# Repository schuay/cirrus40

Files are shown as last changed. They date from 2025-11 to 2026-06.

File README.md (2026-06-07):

# Cirrus40 Keyboard

The Cirrus40 is a 40% split mechanical keyboard, with an ortholinear layout and a focus on usable rotary encoders.

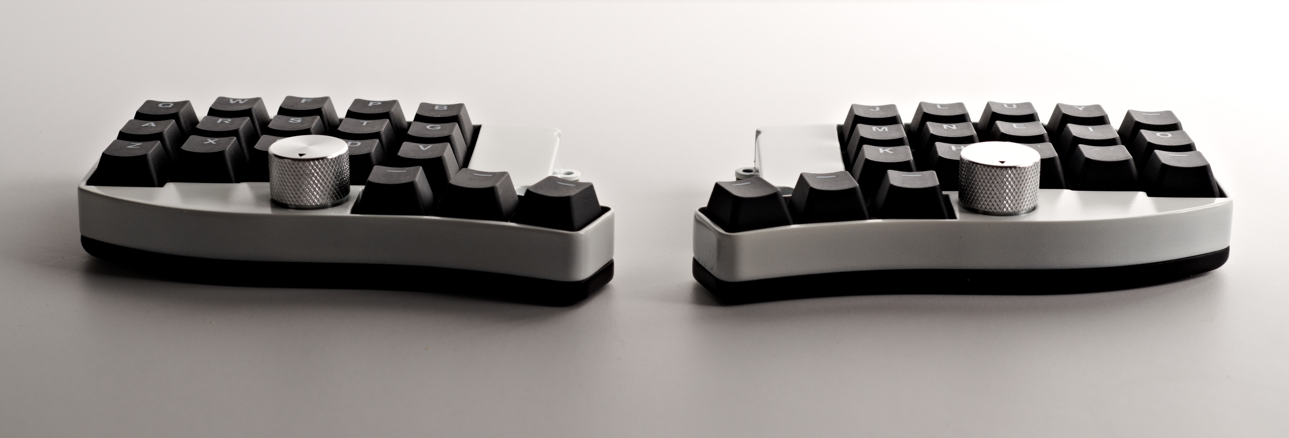
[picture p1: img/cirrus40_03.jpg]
cirrus40img0

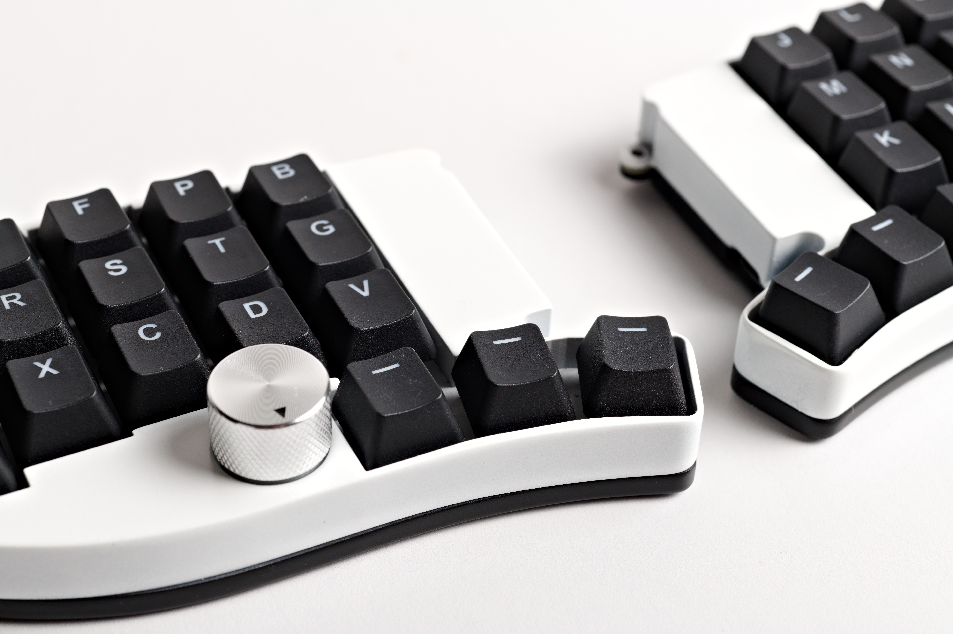
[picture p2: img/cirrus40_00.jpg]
cirrus40img1

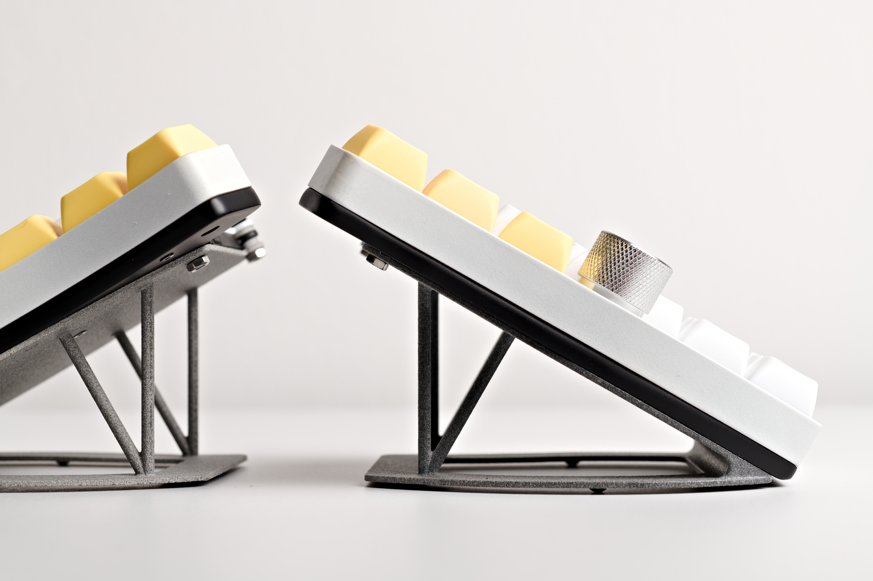
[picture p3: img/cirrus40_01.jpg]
cirrus40img2

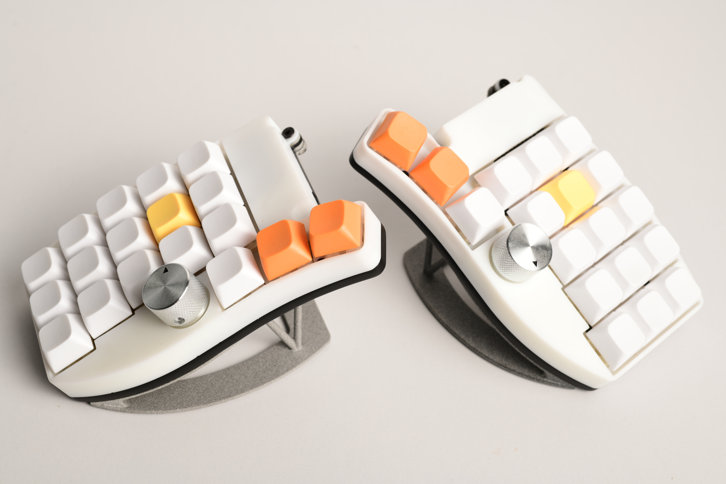
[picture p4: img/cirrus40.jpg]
cirrus40img3

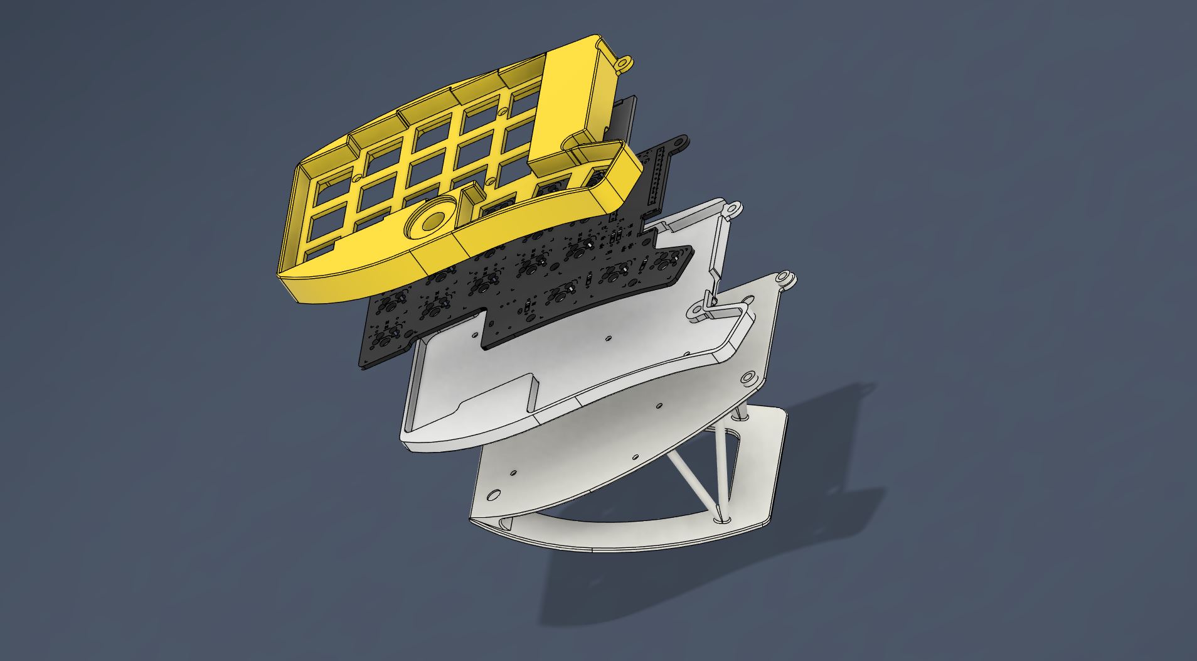
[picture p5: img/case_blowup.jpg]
case_blowup


## Design Considerations

- A **3x thumb cluster** where each key is equally usable and comfortable to reach.
- **Rotary encoders** under the palms are nicely reachable without moving hands from the homerow position. One-handed use together with homerow modifiers (think: switching tabs, workspaces; word-by-word navigation, selection, and deletion). Hardware debouncing for the perfect input signal; no more missed transitions.
- A **full 3d printed case** protects the internals.
- An **optional 3d printed 30deg tenting stand** for rock-solid tenting. The tenting stand integrates perfectly with the case.
- An **ortholinear** layout. Why not columnar stagger: it's comfortable at rest, but increases separation between the pinky and ring fingers in motion.
- A **hot-pluggable wired USB-C interconnect** between halves. USB-C cables are widely available.
- Support for **both wired and wireless** operation.
- Simple tenting using M3 screws.
- No toys: no LEDs, no displays.
- Only widely available and inexpensive parts.

The Cirrus40 combines some of the favorite aspects of my previous builds (the Cheapino's thumb cluster and the Lotus58's key layout and USB-C interconnect). I got a bit fixated on optimizing encoder precision and ergonomics, which is why you'll see the hardware debouncing circuit, the below-palm position, and the strong recommendation for quality Alps encoders.

## Firmware

**QMK**: [qmk_firmware](https://github.com/schuay/qmk_firmware/tree/add_cirrus40). My own keymap is available as an example at [qmk_userspace](https://github.com/schuay/qmk_userspace).

**ZMK**: Contributions welcome. [zmk-config](https://github.com/schuay/zmk-config) hasn't been updated for Cirrus40 Revision 2 yet.

## Required Files

All files required for manufacture are located in the most recent release directory.

- **[PCB Gerber Files](releases/20251220/pcb-gerber.zip)**: For manufacturing the printed circuit boards.
- **[3D Case/Stand Files](releases/20251220/case-steps.tar.xz)**: STEP files for printing the case and optional tenting stand.

## Ordering guide

TLDR: PCB and case manufacturing from JLCPCB, electronics components from LCSC, and the rest from AliExpress with Choice shipping.

- [jlcpcb.com](jlcpcb.com):
  - For the PCB: it's safe to stick with default values. 
  - For the case: I used 9600 Resin (Spray Painting-Matte-Black) for the case and PA12-HP Nylon for the tenting stand with good results. Please let me know if you experiment with other materials.
- [lcsc.com](lcsc.com): See [doc/bom.csv](doc/bom.csv) for more info. Note that the [USB-C connector I used](https://www.lcsc.com/product-detail/C963373.html) is currently out of stock and NOT included in [doc/bom.csv](doc/bom.csv).
- [aliexpress.com](aliexpress.com): Great for switches, keycaps, encoder heads, the RP2040 ProMicro MCU, MCU pin headers, screws, spacers, nuts, etc. I've had good experiences with "Choice" shipping.

Note: jlcpcb.com and lcsc.com offer combined shipping; this is not recommended, as it was more complex, more expensive, and slower when I tried it.

## Build guide

A detailed, step-by-step build guide is not yet available. Contributions on this front are very welcome!

However, the build process is straightforward for those with some experience in hand-soldering keyboards. The soldering difficulty is medium-to-easy; the surface-mount components are in a large (0805) package and are suitable for hand-soldering. The USB-C connector is also simpler than it looks: the wiring is such that all data pins can simply be bridged together (i.e. precise drag-soldering is not strictly needed).

I usually do the USB-C connector and SMD components first, followed by diodes and hotswap sockets; and finally the MCU plus socket and encoders. All components (except the encoder) go on the bottom side of the PCB. Consult the kicad files if something is unclear. A multimeter is good to have around for verification and error search.

## Bill of Materials

A single keyboard build costs around 80EUR including shipping and customs from JLCPCB and LCSC.

**Core Components**
| Part | Quantity | Notes |
| --- | --- | --- |
| Reversible PCB | 2 | From the Gerber files |
| 3D Printed Case | 1 | From the STEP files. Tenting stand is optional. |
| MX switches | 36 | |
| MX hotswap sockets | 36 | |
| EC11 rotary encoders | 2 | **ALPS EC11E15244G1** is strongly recommended. |
| Encoder knobs | 2 | |
| 1N4148 or 1N4148W diodes | 40 | SOD-123 or SOD-323 package |
| 100nF capacitors | 4 | 0805 package |
| 10kOhm resistors | 4 | 0805 package |
| 8.2kOhm resistors | 4 | 0805 package |
| MCU Sockets / Pin Headers | 2 sets | For socketing the microcontrollers |

**Wired Build Components**
| Part | Quantity | Notes |
| --- | --- | --- |
| Pro Micro (RP2040) MCU | 2 | |
| Ferrite beads | 4 | 0805 package, e.g., 220Ω@100MHz |
| USB-C mid-mount connector | 2 | e.g., LCSC C963373 |
| ESD protection diode | 2 | e.g., LCSC C558418 |

**Wireless Build Components**
| Part | Quantity | Notes |
| --- | --- | --- |
| nice!nano v2 MCU | 2 | |
| LiPo Battery | 2 | 301230 (110 mAh) size recommended |
| Power slide switch | 2 | e.g., LCSC C431540 |

**Hardware**
| Part | Quantity | Notes |
| --- | --- | --- |
| M2x4mm screws | 20 | Use M2x6mm for the 4 case holes if using the tenting stand |
| M2x7mm spacers | 10 | |
| M3 screws and nuts | 4 (opt) | For basic, non-stand tenting |

## Release history

Released files can be found in the releases/ directory.

- [releases/20251220](releases/20251220): Revision 2. 3x5+3 with a full 3d printed case and 30deg tenting stand. Hardware encoder debouncing.
- [releases/20251001](releases/20251001): Revision 1. 3x6+3 with a sandwich case.

## Revision 1 Gallery
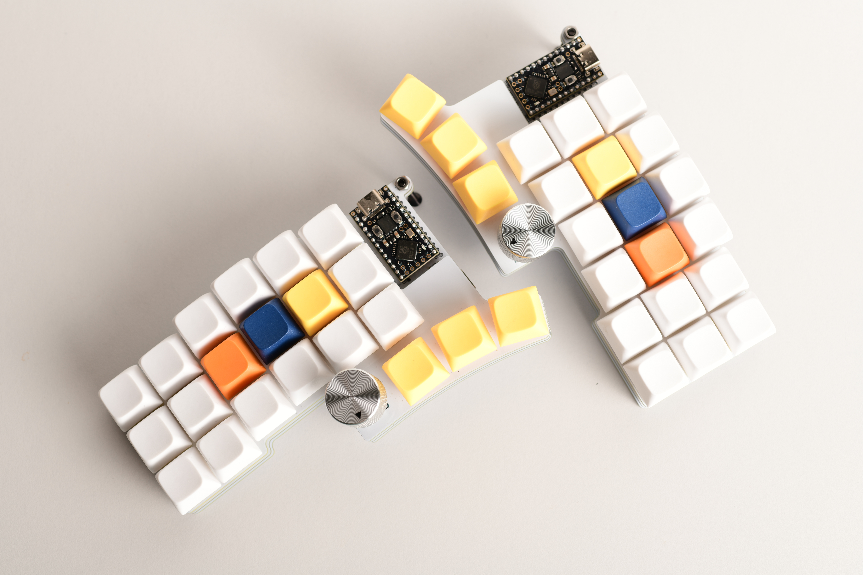
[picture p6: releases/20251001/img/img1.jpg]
cirrus40 img1

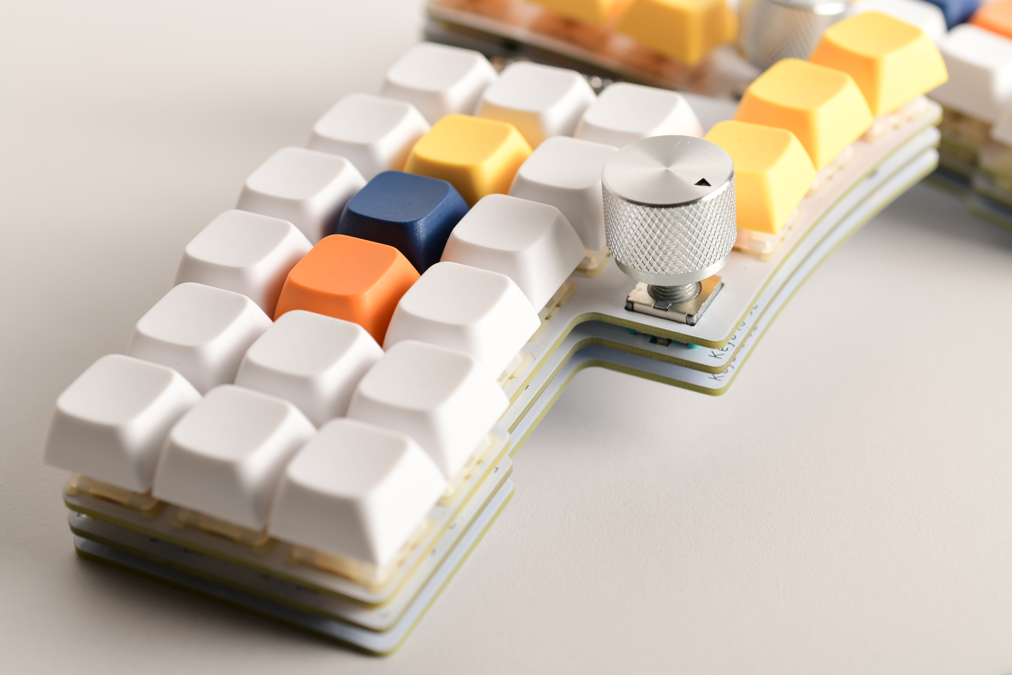
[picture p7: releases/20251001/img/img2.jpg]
cirrus40 img2

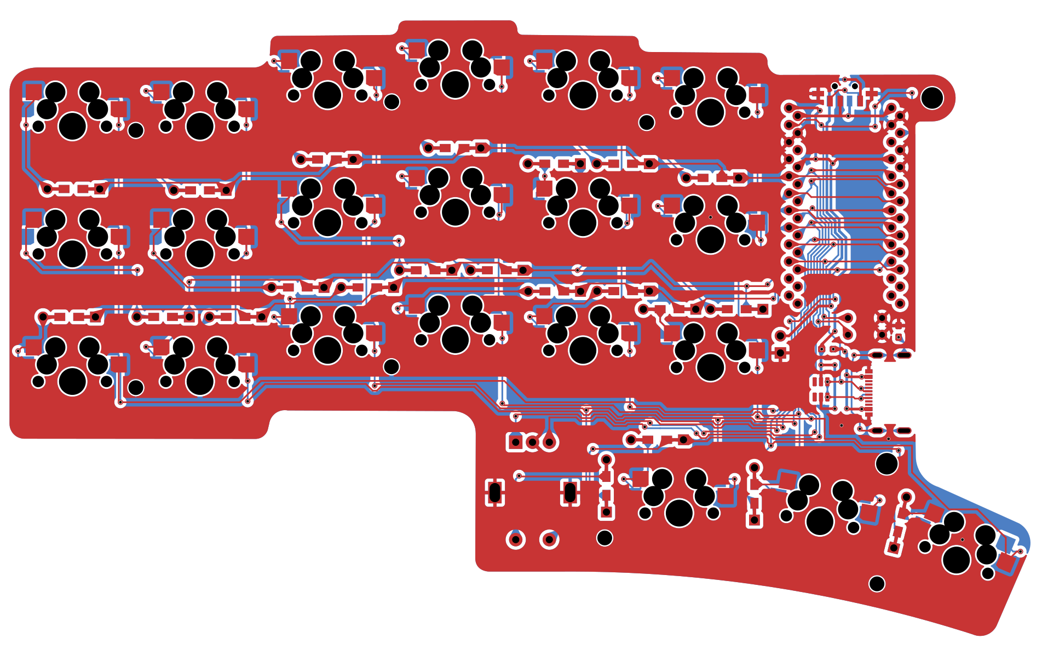
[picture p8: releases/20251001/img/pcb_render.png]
cirrus40 pcb render


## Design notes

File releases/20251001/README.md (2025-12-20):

# Cirrus40 Keyboard

The Cirrus40 is a 40% split mechanical keyboard, featuring an ortholinear layout and rotary encoders designed as first-class citizens.

cirrus40 img1
cirrus40 img2

## Design Considerations

- A **3x thumb cluster** where each key is equally usable and comfortable to reach.
- **Rotary encoders** under the palms are nicely reachable without moving hands from the homerow position. One-handed use together with homerow modifiers (think: switching tabs, workspaces; word-by-word navigation, selection, and deletion).
- An **ortholinear** layout. Why not columnar stagger: it's comfortable at rest, but increases separation between the pinky and ring fingers in motion.
- A **hot-pluggable wired interconnect** between halves, since it's not acceptable that unplugging a cable at the wrong time can destroy your keyboard.
- Support for **both wired and wireless** operation. For wired: the interconnect is ESD protected. For wireless: the battery can be physically disconnected using a switch.
- Simple tenting using M3 screws.
- No toys: no LEDs, no displays.
- Only widely available and inexpensive parts.

cirrus40 pcb render

## Why not..

There are many great keyboard designs out there. But keyboards are highly personal, and none of them hit all the marks for me. So why not...

- The **cheapino**: this was the first keyboard I built. It's very beginner friendly due to the large components and a great first build. However, since the entire matrix is routed onto one MCU, and particularly since the RJ45 only has 7 pins available for signals, the design has to make compromises such as the duplex matrix, and connecting the rotary encoder through the matrix instead of dedicated pins. Also, there is only one encoder in an inconvenient position, and I didn't like the
  columnar stagger. The thumb cluster is great though, and I've reused it here.
- **Lotus58**: Inconvenient thumb cluster and encoder placement, a number row, and unnecessary features like displays and LEDs. I learnt a lot from this design though, particularly the USB-C interconnect design was lifted from here.
- **Kyria**: I was eyeing this one for a while, and I love the design decisions. But, it's not open source. Also, the palm encoder position is too far away from the thumb, and it uses pronounced columnar stagger.
- **Corne**: Only two usable thumb keys, and recent versions require expensive factory assembly.
- Any pure wireless keyboard: unfortunately ZMK is not as mature as I'd hoped.

## Release history

Released files can be found in the releases/ directory.

- [releases/20251220](releases/20251220): Revision 2. 3x5+3 with a full 3d printed case and 30deg tenting stand. Hardware encoder debouncing.
- [releases/20251001](releases/20251001): Revision 1. 3x6+3 with a sandwich case.

## Bill of Materials

- 2 each of the PCB, and top and bottom plates
- 42 MX switches and keycaps
- 42 MX hotswap sockets
- 2 EC11 encoders and encoder heads
- 44 1N4148 or 1N4148W diodes
- 4 100nF capacitors
- MCU sockets

For the wired build, additionally:
- 2 RP2040 Pro Micro MCUs
- 4 20mΩ 70Ω@100MHz 0603 ferrite beads
- 2 USB-C midmount connectors, e.g. https://www.lcsc.com/product-detail/C963373.html
- 2 ESD diodes, e.g. https://www.lcsc.com/product-detail/C558418.html

For the wireless build, additionally:
- 2 nice!nano v2 MCUs
- 2 Lithium-Polymer Battery 301230 (110 mAh)
- 2 slide switches: https://www.lcsc.com/product-detail/C431540.html

For assembly:
- 28 M2x4mm screws
- 14 M2x3mm spacers
- 4 M3 screws and nuts for tenting

Note you can simply combine both builds if you're undecided and want to be able to swap MCUs and batteries.

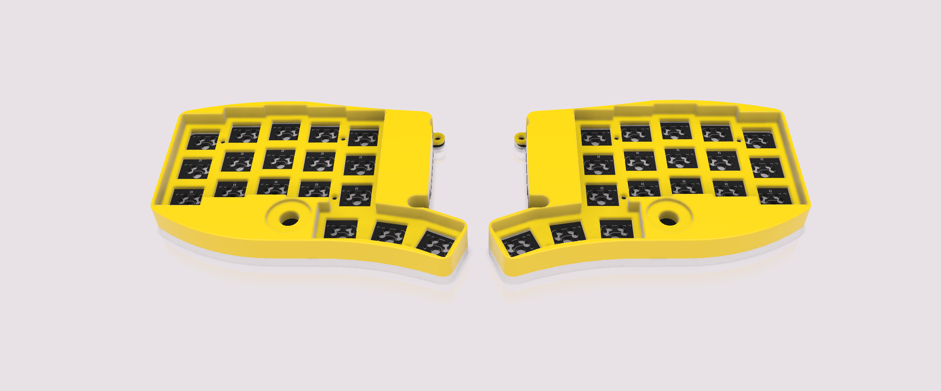
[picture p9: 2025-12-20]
img/case_render.png

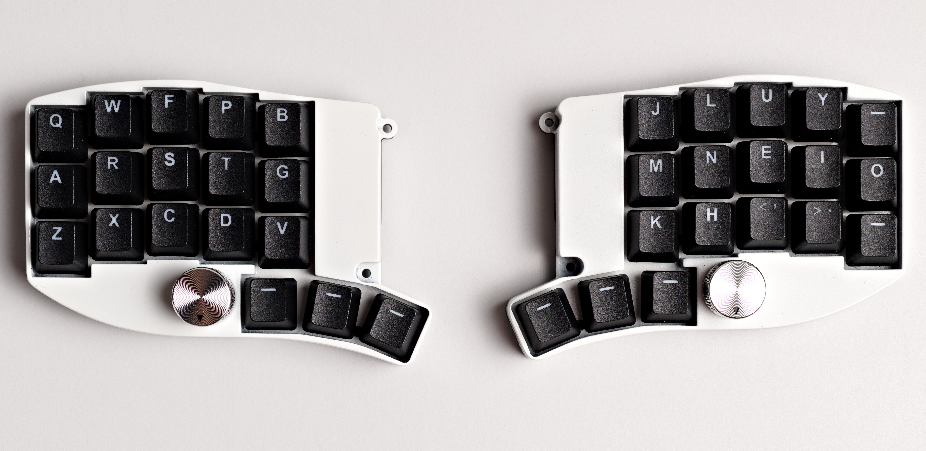
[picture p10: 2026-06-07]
img/cirrus40_04.jpg

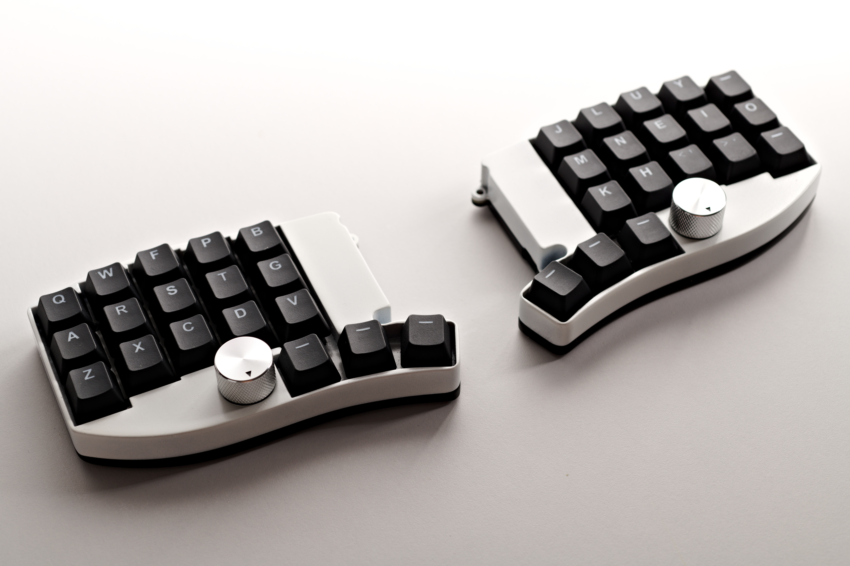
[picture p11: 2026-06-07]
img/cirrus40_02.jpg

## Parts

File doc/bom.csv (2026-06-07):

Cirrus40v2 |  |  |  |  |  |  |  |  |  | LCSC BOM Quotation
 |  |  |  |  |  |  |  |  |  | BOM Date Created：31/12/25 17:56:03 |  |  |  | BOM Export Date: 31/12/25 18:03:18 |  |  |  | The matching result is a real-time query result, availability and prices may fluctuate. Backorder items are estimated prices for your reference, please submit "Create Quote" to get the real price. All information is provided "as is" and is subject to change without notice. Any use made of the information provided is without recourse to LCSC and at the user's risk.
 |  |  |  |  |  |  |  |  |  | EST TOTAL :$6.07 |  |  |  | Website：https://www.lcsc.com/bom
Uploaded data |  |  |  |  |  |  |  |  |  | LCSC Matching Results
LCSC# | Mfr. | Mrf# | Description | Package | Value | Customer Part Number | Quantity | Target Price(EUR) | Target Lead Time(Business Days) | Mrf# | Mfr. | Order Qty. | Unit Price(EUR) | Ext.Price(EUR) | LCSC# | Package | Min | Mult | SPQ | Availability | Stock Status | Customer Notes | Description | Matched status | Product Link
 |  |  |  |  |  | - | 2 |  |  | EC11E15244G1 | ALPSALPINE | 2 | 1.8759 | 3.75 | C370970 | Through Hole | 1 | 1 | 120 | 2121 | In Stock |  | Through Hole Encoders RoHS | Exact Matches | https://www.lcsc.com/product-detail/C370970.html
 |  |  |  |  |  | - | 4 |  |  | CC0805KRX7R9BB104 | YAGEO | 100 | 0.0043 | 0.43 | C49678 | 0805 | 100 | 100 | 4000 | 8486200 | In Stock |  | 100nF ±10% 50V Ceramic Capacitor X7R 0805 | Exact Matches | https://www.lcsc.com/product-detail/C49678.html
 |  |  |  |  |  | - | 4 |  |  | BLM21PG221SN1D | muRata | 50 | 0.0145 | 0.73 | C85840 | 0805 | 50 | 50 | 4000 | 1164100 | In Stock |  | 220Ω@100MHz 1 Line Ferrite Bead 0805 2A 45mΩ | Exact Matches | https://www.lcsc.com/product-detail/C85840.html
 |  |  |  |  |  | - | 4 |  |  | RS-05K1002FT | FH | 100 | 0.0018 | 0.18 | C115309 | 0805 | 100 | 100 | 5000 | 1124300 | In Stock |  | 10kΩ ±1% 125mW 0805 Thick Film Resistor | Exact Matches | https://www.lcsc.com/product-detail/C115309.html
 |  |  |  |  |  | - | 4 |  |  | 0805W8F8201T5E | UNI-ROYAL | 100 | 0.0017 | 0.17 | C17828 | 0805 | 100 | 100 | 5000 | 353200 | In Stock |  | 8.2kΩ ±1% 125mW 0805 Thick Film Resistor | Exact Matches | https://www.lcsc.com/product-detail/C17828.html
 |  |  |  |  |  | - | 40 |  |  | 1N4148 | LGE | 50 | 0.0079 | 0.40 | C402212 | DO-35 | 50 | 50 | 5000 | 82100 | In Stock |  | Diode 75V 150mA Through Hole DO-35 | Exact Matches | https://www.lcsc.com/product-detail/C402212.html
 |  |  |  |  |  | - | 2 |  |  | SRV05-4 | TECH PUBLIC | 20 | 0.0206 | 0.41 | C558418 | SOT-23-6 | 20 | 20 | 3000 | 183460 | In Stock |  | 20VC Clamp 3A Ipp ESD DIODE SOT-23-6 | Exact Matches | https://www.lcsc.com/product-detail/C558418.html

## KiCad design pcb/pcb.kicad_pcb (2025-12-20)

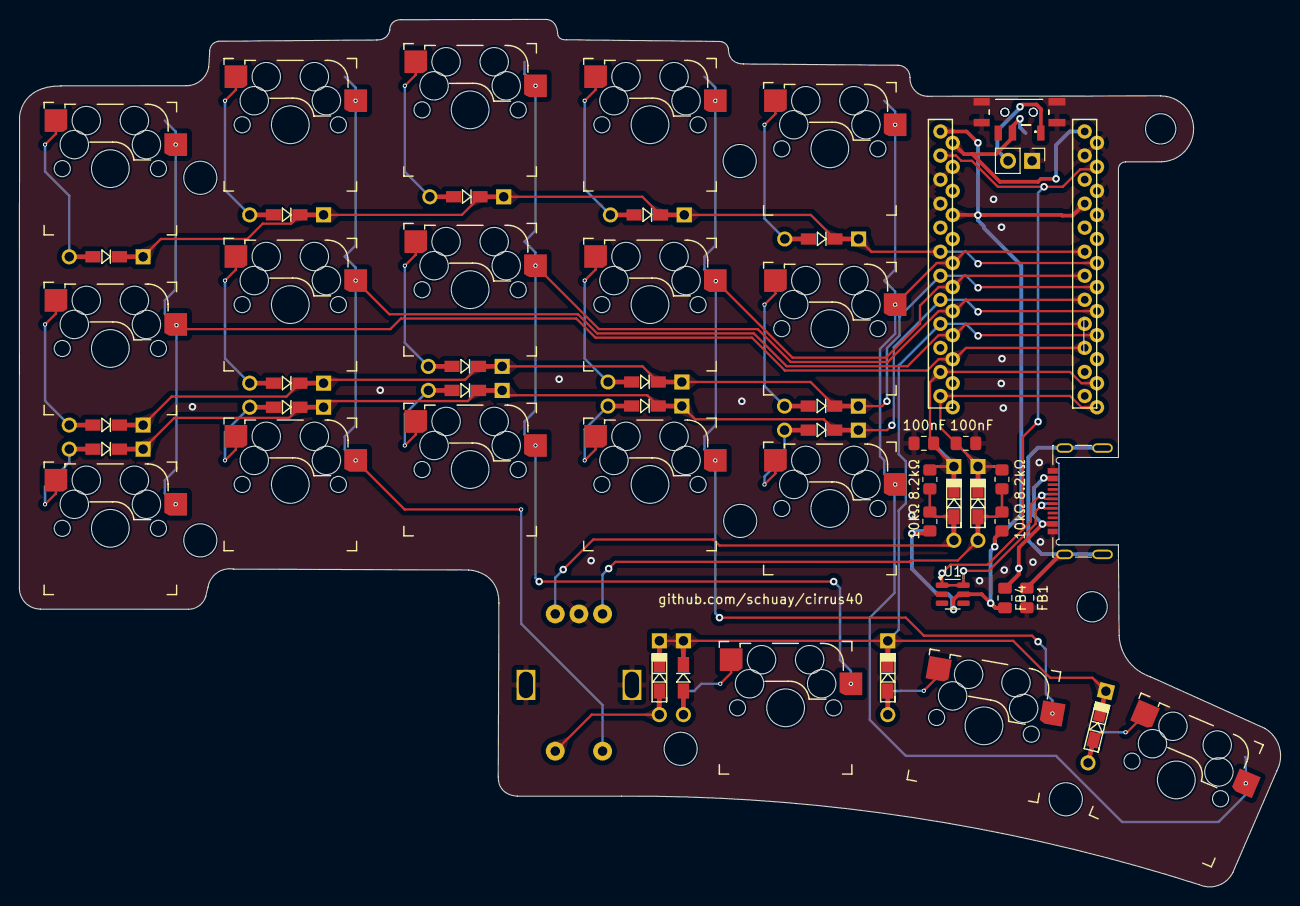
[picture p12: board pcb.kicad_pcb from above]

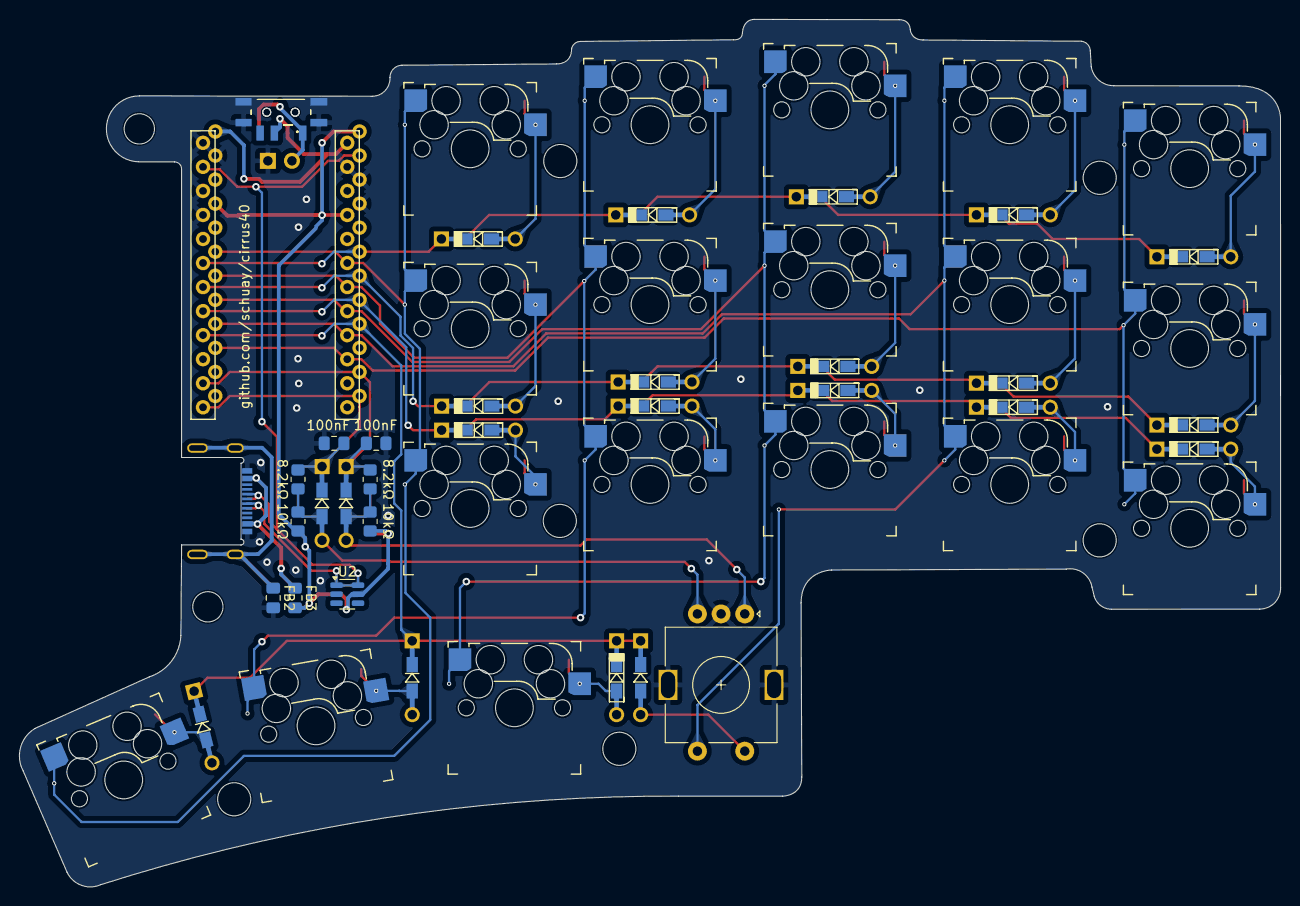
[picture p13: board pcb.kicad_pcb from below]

Board: 2 copper layers, 133.2 x 91.6 mm, 63 parts (45 on the bottom side), 39 nets.

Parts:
8.2kΩ, 8.2kΩ#2, 8.2kΩ#3, 8.2kΩ#4: 8kOhm; R_0805_2012Metric_Pad1.20x1.40mm_HandSolder
10kΩ, 10kΩ#2, 10kΩ#3, 10kΩ#4: 10kOhm; R_0805_2012Metric_Pad1.20x1.40mm_HandSolder
100nF, 100nF#2, 100nF#3, 100nF#4: 470nF; C_0805_2012Metric_Pad1.18x1.45mm_HandSolder
D1, D2, D3, D4, D5, D6, D7, D8, D9, D10, D11, D12, D13, D14, D15, D16, D17, D18, D19, D20, D21: DIODE; Diode-dual
ENC1: RotaryEncoder_Switch_MP; RotaryEncoder_Alps_EC11E-Switch_Vertical_H20mm
FB1, FB2, FB3, FB4: Ferrite Bead; C_0805_2012Metric_Pad1.18x1.45mm_HandSolder
J1: USB_C_Receptacle_USB2.0_16P; Molex-216990_GCT-USB45xx_HRO-TYPE-C-31-M-13x-PiMicro_1_DOUB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
J2: Conn_01x02; PinHeader_1x02_P2.54mm_Vertical
K1, K2, K3, K4, K5, K6, K7, K8, K9, K10, K11, K12, K13, K14, K15, K16, K17, K18: SW_Push; SW_MX_HotSwap_Reversible
S1, S2: MSK12C02
U1, U2: SRV05-4; SOT-23-6
U3: ProMicro; ProMicro_Reversible_orig

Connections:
/Batt: J2.2, S1.NC, S2.NC
/VCC_LINK: FB3.1, FB4.1, J1.A4 (VBUS), J1.A9 (VBUS), J1.B4 (VBUS), J1.B9 (VBUS)
Battery: S1.COM, S2.COM, U3.5V
COL0: K15.1, K16.1, K17.1, K18.1, U3.28 (GP28)
COL1: K11.1, K12.1, K13.1, K14.1, U3.27 (GP27)
COL2: K7.1, K8.1, K9.1, K10.1, U3.26 (GP26)
COL3: ENC1.S1, K4.1, K5.1, K6.1, U3.22 (GP22)
COL4: K1.1, K2.1, K3.1, U3.20 (GP20)
DATA: J1.A7 (D-), J1.B7 (D-), U1.1 (IO1), U1.6 (IO4), U2.1 (IO1), U2.6 (IO4), U3.1 (GP1)
ENCA: 8.2kΩ#2.1, 8.2kΩ#3.1, 10kΩ#2.2, 10kΩ#4.2, D12.1 (K), ENC1.A
ENCA_DB: 8.2kΩ#2.2, 8.2kΩ#3.2, 100nF#2.1, 100nF#3.1, D12.2 (A), U3.8 (GP8)
ENCB: 8.2kΩ.1, 8.2kΩ#4.1, 10kΩ.2, 10kΩ#3.2, D21.1 (K), ENC1.B
ENCB_DB: 8.2kΩ.2, 8.2kΩ#4.2, 100nF.1, 100nF#4.1, D21.2 (A), U3.9 (GP9)
GND: 100nF.2, 100nF#2.2, 100nF#3.2, 100nF#4.2, ENC1.C, ENC1.MP, FB1.2, FB2.2, J1.A1 (GND), J1.A12 (GND), J1.B1 (GND), J1.B12 (GND), J2.1, S1.MP (GND), S2.MP (GND), U1.2 (VN), U2.2 (VN), U3.0 (GP0), U3.GND
unnamed: D1.1 (K), K1.2
unnamed: D2.1 (K), K2.2
unnamed: D3.1 (K), K3.2
unnamed: D4.1 (K), K4.2
unnamed: D5.1 (K), K5.2
unnamed: D6.1 (K), K6.2
unnamed: D7.1 (K), ENC1.S2
unnamed: D8.1 (K), K7.2
unnamed: D9.1 (K), K8.2
unnamed: D10.1 (K), K9.2
unnamed: D11.1 (K), K10.2
unnamed: D13.1 (K), K11.2
unnamed: D14.1 (K), K12.2
unnamed: D15.1 (K), K13.2
unnamed: D16.1 (K), K14.2
unnamed: D17.1 (K), K15.2
unnamed: D18.1 (K), K16.2
unnamed: D19.1 (K), K17.2
unnamed: D20.1 (K), K18.2
unnamed: FB1.1, FB2.1, J1.S1 (SHIELD)
ROW0: D1.2 (A), D4.2 (A), D8.2 (A), D13.2 (A), D17.2 (A), U3.3 (GP3)
ROW1: D2.2 (A), D5.2 (A), D9.2 (A), D14.2 (A), D18.2 (A), U3.4 (GP4)
ROW2: D3.2 (A), D6.2 (A), D10.2 (A), D15.2 (A), D19.2 (A), U3.5 (GP5)
ROW3: D7.2 (A), D11.2 (A), D16.2 (A), D20.2 (A), U3.6 (GP6)
VCC: 10kΩ.1, 10kΩ#2.1, 10kΩ#3.1, 10kΩ#4.1, FB3.2, FB4.2, U1.5 (VP), U2.5 (VP), U3.3V3, U3.99 (GP0L)

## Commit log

2025-11-02 cirrus40, second manufactured version
    [case.FCStd, pcb.kicad_pcb, pcb.kicad_sch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]
2025-11-06 add case files
    [case.FCStd]
2025-12-20 add cap/resistor labels and github link
    [pcb.kicad_pcb, pcb.kicad_sch]
2025-12-20 update for revision 2
    [plate-bottom.kicad_pcb, plate-mcu.kicad_pcb, plate-top.kicad_pcb]
2026-06-07 extend documentation
    [bom.csv]
